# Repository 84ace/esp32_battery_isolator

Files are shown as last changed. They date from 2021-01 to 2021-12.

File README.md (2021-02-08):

<!-- PROJECT SHIELDS -->
<!--
*** I'm using markdown "reference style" links for readability.
*** Reference links are enclosed in brackets [ ] instead of parentheses ( ).
*** See the bottom of this document for the declaration of the reference variables
*** for contributors-url, forks-url, etc. This is an optional, concise syntax you may use.
*** https://www.markdownguide.org/basic-syntax/#reference-style-links
-->
[][contributors-url]
[][forks-url]
[][stars-url]
[][issues-url]
[][license-url]
[][linkedin-url]

<!-- PROJECT LOGO -->
<br />
<p align="center">
  <a href="https://github.com/84ace/esp32_battery_isolator">
    
  </a>

  <h3 align="center">ESP32 Battery Isolator</h3>

  <p align="center">
    Off-road battery management
    <br />
    <a href="https://github.com/84ace/esp32_battery_isolator/wiki"><strong>Explore the docs »</strong></a>
    <br />
    <br />
    <a href="https://github.com/84ace/esp32_battery_isolator/tree/master/board_images">Board Images</a>
    ·
    <a href="https://github.com/84ace/esp32_battery_isolator/issues">Report Bug</a>
    ·
    <a href="https://github.com/84ace/esp32_battery_isolator/issues">Request Feature</a>
  </p>
</p>

<!-- TABLE OF CONTENTS -->
<details open="open">
  <summary>Table of Contents</summary>
  <ol>
    <li>
      <a href="#about-the-project">About The Project</a>
      <ul>
        <li><a href="#main-features">Main Features</a></li>
        <li><a href="#whats-missing">What's Missing</a></li>
      </ul>
    </li>
    <li>
      <a href="#get-the-isolator">Get the Isolator</a>
    </li>
    <li><a href="#roadmap">Roadmap</a></li>
    <li><a href="#contributing">Contributing</a></li>
    <li><a href="#made-with">Made with</a></li>
    <li><a href="#license">License</a></li>
    <li><a href="#contact">Contact</a></li>
    <li><a href="#acknowledgements">Acknowledgements</a></li>
  </ol>
</details>

<!-- ABOUT THE PROJECT -->
## About The Project

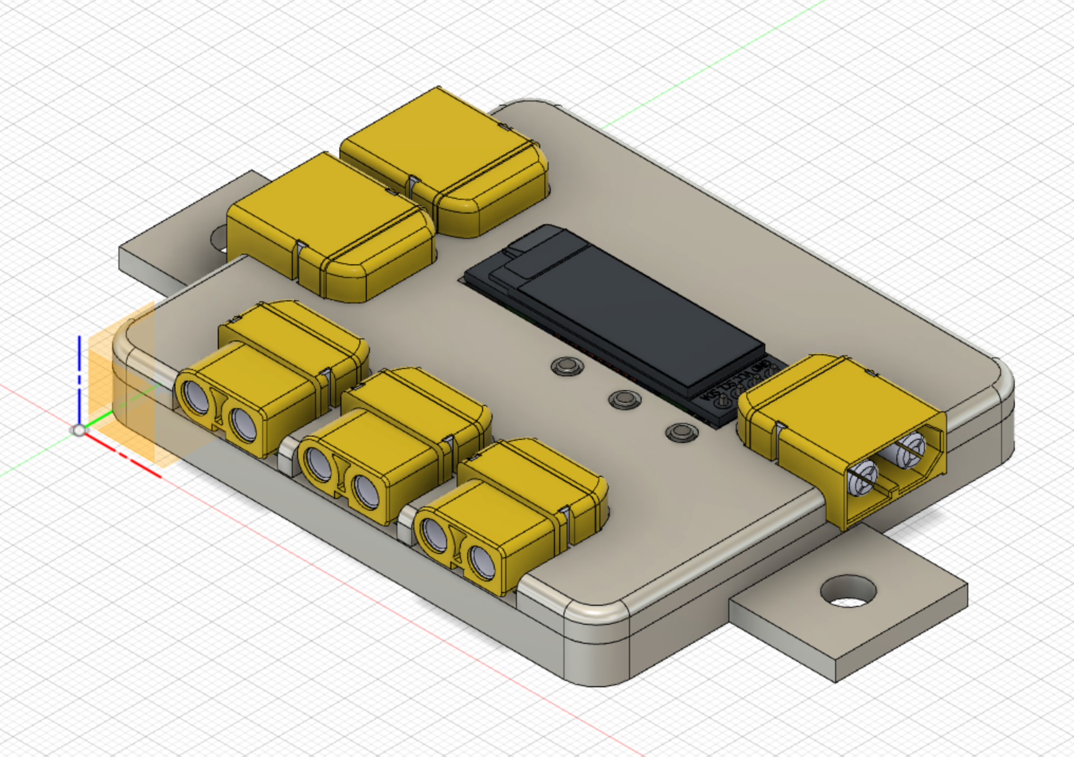
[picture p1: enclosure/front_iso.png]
ESP32 Battery Isolator
[](https://github.com/84ace/esp32_battery_isolator/raw/master/enclosure/front_iso.png)

The ESP32 Battery Isolator was created so that I could have better control over battery and load isolation, and because I thought it would be an interesting project that would allow me to learn a few new things. 

I also thought that I should be able to turn the lights off in camp from the comfort of bed, rather than having to turn the lights off and walk to bed in the dark and probably kick my toe.

<!-- MAIN FEATURES -->
## Main Features:
* Dual battery input
* Triple load output
* Charger input (From external MPPT/solar charge controller)
* Current sensors
* Temperature sensor
* 128x32 OLED screen
* Bluetooth (for remote control via phone app)
* WiFi (for debugging)
* USB (micro)
* 30A continuous operation

<!-- WHAT"S MISSING -->
## What's missing:
* A Phone app for remote control / live telemetry

If you would like to contribute an app please contact me via the <a href="https://github.com/84ace/esp32_battery_isolator/tree/master/board_images">issues</a> page.

<!-- GETTING STARTED -->
## Get the Isolator

There are two ways to get started with the ESP32 Battery Isolator: 
* You can either take the easy(er) way and buy a pre-made unit from [here](https://placeholder.com/) 
* you can send the gerber files off to your favourite fab house, order the components, assemble the board and print the enclosure yourself.

Your choice!

<!-- ROADMAP -->
## Roadmap

See the [open issues](https://github.com/84ace/esp32_battery_isolator/issues) for a list of proposed features (and known issues).

<!-- CONTRIBUTING -->
## Contributing

Contributions are what make the open source community such an amazing place to be learn, inspire, and create. Any contributions you make are **greatly appreciated**.

1. Fork the Project
2. Create your Feature Branch (`git checkout -b feature/AmazingFeature`)
3. Commit your Changes (`git commit -m 'Add some AmazingFeature'`)
4. Push to the Branch (`git push origin feature/AmazingFeature`)
5. Open a Pull Request

<!-- MADE WITH -->
## Made With:
* [KiCad - Electronic Design Automation Suite](https://kicad.org/)
* [Fusion360 - CAD Software](https://www.autodesk.com.au/products/fusion-360/overview)
* [JLCPCB - PCB Fabrication Manufacturer](https://jlcpcb.com/)

<!-- LICENSE -->
## License

Distributed under the MIT License. See `LICENSE` for more information.

<!-- CONTACT -->
## Contact

84ace - [@Racea_Quigg](https://twitter.com/@RaceaQuigg)

Project Link: [https://github.com/84ace/esp32_battery_isolator](https://github.com/84ace)

<!-- MARKDOWN LINKS & IMAGES -->
<!-- https://www.markdownguide.org/basic-syntax/#reference-style-links -->
[contributors-shield]: https://img.shields.io/github/contributors/84ace/esp32_battery_isolator.svg?style=for-the-badge
[contributors-url]: https://github.com/84ace/esp32_battery_isolator/graphs/contributors
[forks-shield]: https://img.shields.io/github/forks/84ace/esp32_battery_isolator.svg?style=for-the-badge
[forks-url]: https://github.com/84ace/esp32_battery_isolator/network/members
[stars-shield]: https://img.shields.io/github/stars/84ace/esp32_battery_isolator.svg?style=for-the-badge
[stars-url]: https://github.com/84ace/esp32_battery_isolator/stargazers
[issues-shield]: https://img.shields.io/github/issues/84ace/esp32_battery_isolator.svg?style=for-the-badge
[issues-url]: https://github.com/84ace/esp32_battery_isolator/issues
[license-shield]: https://img.shields.io/github/license/84ace/esp32_battery_isolator.svg?style=for-the-badge
[license-url]: https://github.com/84ace/esp32_battery_isolator/blob/master/LICENSE.txt
[linkedin-shield]: https://img.shields.io/badge/-LinkedIn-black.svg?style=for-the-badge&logo=linkedin&colorB=555
[linkedin-url]: https://www.linkedin.com/in/acea-quigg-2007036b/
[product-screenshot]: enclosure/front_iso.png

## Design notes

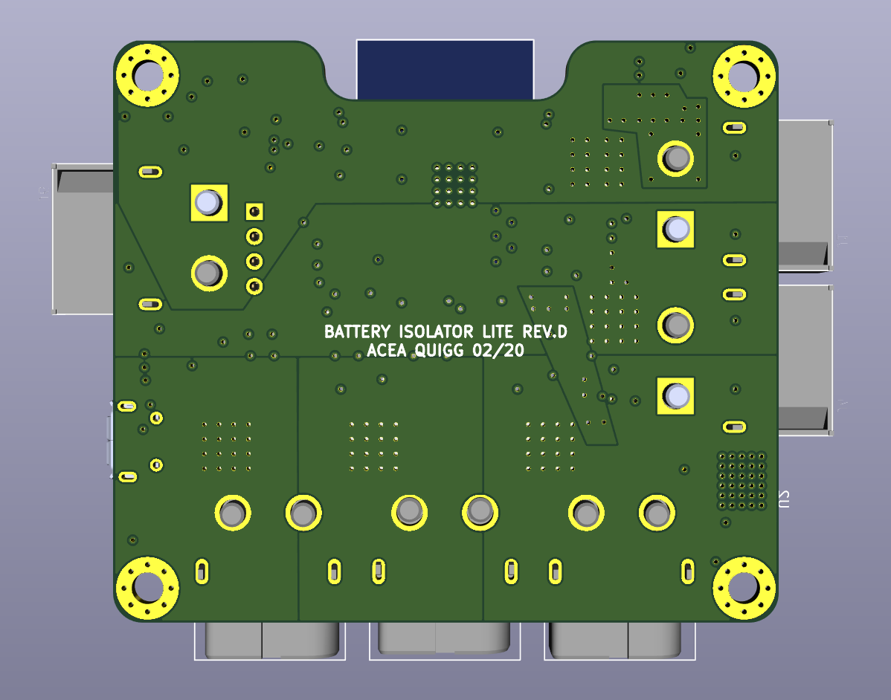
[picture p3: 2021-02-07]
board_images/back.png

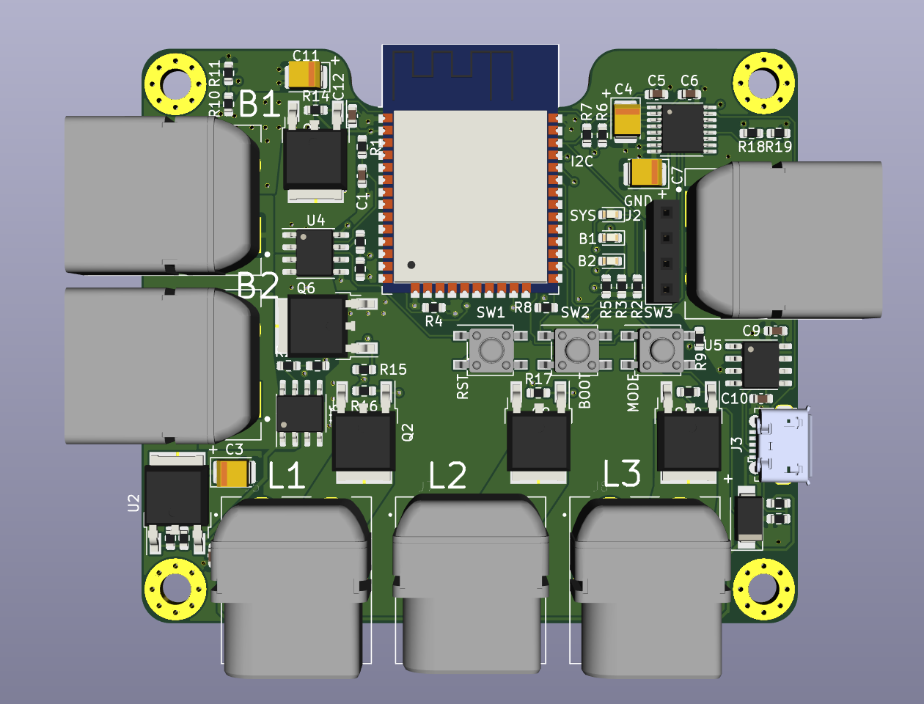
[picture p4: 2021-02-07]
board_images/front.png

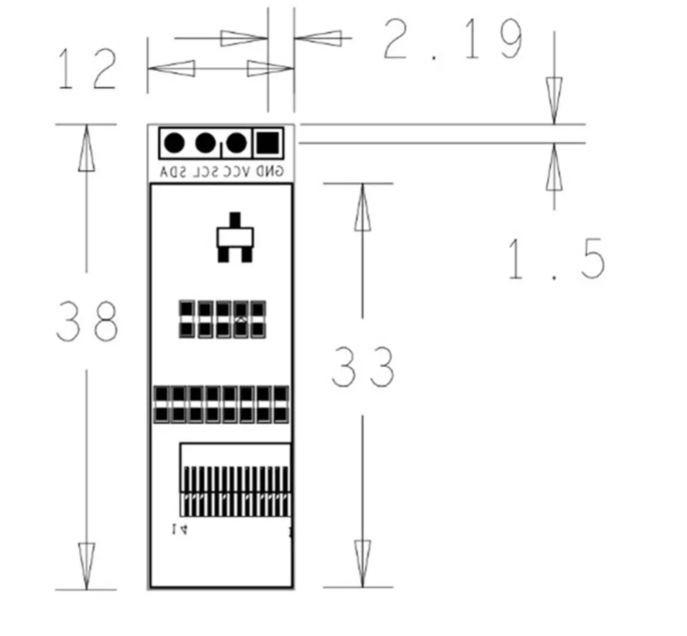
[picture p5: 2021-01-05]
enclosure/OLED_dimensions.png

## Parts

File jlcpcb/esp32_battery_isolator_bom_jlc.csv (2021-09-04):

Comment | Designator | Footprint | LCSC Part #
10nF | C2 | C_0603_1608Metric | C57112
220uF | C3 | C_Elec_6.3x7.7 | C371974
1uF | C4,C7 | CP_EIA-3528-21_Kemet-B | C169224
220uF | C8 | CP_EIA-3528-15_AVX-H | C30242
100n | C12,C1,C5,C6,C10,C9 | C_0603_1608Metric | C14663
4.7uF | C15 | C_0805_2012Metric | C1779
SS34 | D1 | D_SMA | C8678
LED_Small | D4 | LED_0603_1608Metric | C2286
B5819W | D8,D9,D3,D2 | D_SOD-123 | C8598
BATT1 | J1 | AMASS_XT60PW-M | C98732
USB_B_Micro | J3 | USB_Micro_SHOU-HAN-MicroXNJ_C404969_Horizontal | C404969
BATT2 | J4 | AMASS_XT60PW-M | C98732
LOAD1 | J5 | AMASS_XT60PW-F | C428722
CHGR | J6 | AMASS_XT60PW-M | C98732
LOAD2 | J7 | AMASS_XT60PW-F | C428722
LOAD3 | J8 | AMASS_XT60PW-F | C428722
Conn_01x03_Male | J9 | JST_SH_SM03B-SRSS-TB_1x03-1MP_P1.00mm_Horizontal | C160403
47uH | L1 | L_Bourns_SRN6045TA | C36414
MMBT3904 | Q1,Q7,Q9,Q5,Q12,Q3 | SOT-23 | C20526
AONR21321 | Q2,Q8,Q10,Q6,Q4,Q11,Q13 | TRANS_AONR21321 | C431196
200k | R10,R12,R20,R17,R16,R14,R15 | R_0603_1608Metric | C25811
33k | R11,R13 | R_0603_1608Metric | C4216
3.6k | R18,R21,R23,R6,R7,R3 | R_0603_1608Metric | C22980
11k | R19,R22,R24,R1,R8,R4,R2,R9,R5,R25,R26,R33,R32 | R_0603_1608Metric | C25950
510R | R27,R29,R28,R30,R31 | R_0603_1608Metric | C269885
C492887 | SW1,SW2 | TS4550TP | C492887
ESP32-WROOM-32D | U1 | ESP32-WROOM-32 | C473012
XL1509_SOP8 | U2 | SOIC-8_3.9x4.9mm_P1.27mm | C2681226
ADC128D818 | U3 | TSSOP-16_4.4x5mm_P0.65mm | C139062
CH340N | U5 | SOIC-8_3.9x4.9mm_P1.27mm | C506813
CC6903SO-30A | U6,U4 | SOP-8_3.9x4.9mm_P1.27mm | C469388

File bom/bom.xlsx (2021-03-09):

References | lcsc_part_number | Value | Footprint | Quantity
C1, C2, C5, C6, C9, C10, C12 | C14663 | 100n | C_0603_1608Metric | 7
C3, C4, C7, C11 | C169224 | 1uF | CP_EIA-3528-21_Kemet-B | 4
R11, R13 | C4216 | 33k | R_0603_1608Metric | 2
R2, R3, R5, R6, R7, R18, R21, R23 | C22980 | 3.6k | R_0603_1608Metric | 8
R26 | C23138 | 330R | R_0603_1608Metric | 1
R10, R12, R14, R15, R16, R17, R20 | C25811 | 200k | R_0603_1608Metric | 7
R1, R4, R8, R9, R19, R22, R24 | C25950 | 11k | R_0603_1608Metric | 7
R25 | C8218 | 200R | R_0603_1608Metric | 1
D1, D3, D4 | C2286 | MAIN LED | LED_0603_1608Metric | 3
D2 | C2480 | SS14 | D_SMA | 1
U5 | C108996 | CH330N | SOIC-8_3.9x4.9mm_P1.27mm | 1
U3 | C139062 | ADC128D818 | TSSOP-16_4.4x5mm_P0.65mm | 1
U4, U6 | C469388 | CC6903SO-30A | SOP-8_3.9x4.9mm_P1.27mm | 2
U1 | C473012 | ESP32-WROOM-32D | ESP32-WROOM-32 | 1
U2 | C75510 | LM317AG-TN3-R | TO-252-2 | 1
SW1, SW2, SW3 | C492887 | C492887 | TS4550TP | 3
Q2, Q4, Q6, Q8, Q10 | C124530 | AP6679GH-HF | TO-252-2 | 5
J2 |  | Conn_01x04_Female | PinSocket_1x04_P2.54mm_Vertical | 1
J3 | C404969 | USB_B_Micro | USB_Micro_SHOU-HAN-MicroXNJ_C404969_Horizontal | 1
J5 | C428722 | LOAD1 | AMASS_XT60PW-F | 1
J7 | C428722 | LOAD2 | AMASS_XT60PW-F | 1
J8 | C428722 | LOAD3 | AMASS_XT60PW-F | 1
J1 | C98732 | BATT1 | AMASS_XT60PW-M | 1
J4 | C98732 | BATT2 | AMASS_XT60PW-M | 1
J6 | C98732 | CHGR | AMASS_XT60PW-M | 1

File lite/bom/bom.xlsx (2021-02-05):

References | lcsc_part_number | mfr_part_number | package | Value | Footprint | Quantity
BI:C1, C5, C6, C12, C9, C10 | C128353 | 0805B104K250 | 0805 | 100n | C_0805_2012Metric | 6
BI:C2, C3 | C23289 | RVT1V220M0505 | 5x5.4 | 22uF 35V | C_Elec_5x5.4 | 2
BI:C4, C7, C11 | C126949 | CA45-A035K105T | CASE_A_3216 | 1uF | CP_EIA-3216-18_Kemet-A | 3
BI:D1, D3, D4 | C72044 | 19-217/R6C-AL1M2VY/3T | 0603 | RED LEDs | LED_0603_1608Metric | 1
BI:D2 | C2480 | SS14 | SMA | SS14 | D_SMA | 1
BI:J3 | C319172 | U253-051T-4BH89-F1B | micro_usb | USB_B_Micro | USB_Micro-B_XKB_4BH89_SMT | 1
BI:J1,J4, J6 | C98733 (https://lcsc.com/product-detail/Power-Connectors_Changzhou-Amass-Elec-XT60_C98733.html) | XT60-F |  | BATT2 | AMASS_XT60-F_1x02_P7.20mm_Vertical | 3
BI:J5, J7, J8 | C98734 | XT60-M |  | LOAD1 | AMASS_XT60-M_1x02_P7.20mm_Vertical | 3
BI:Q2, Q4, Q6, Q8, Q10 | C148395 | WSD20L120DN | SON8 | WSD20L120DN | PowerPAK_SO-8_Single | 5
BI:R1, R4, R8, R9, R19, R22, R24 | C705802 | RT0603BRE0710K2L | 0603 | 10k2 | R_0603_1608Metric | 7
BI:R10, R12, R14, R15, R16, R17, R20 | C491109 | ERA3AEB1053V | 0603 | 105k | R_0603_1608Metric | 7
BI:R11, R13 | C319766 | AR03BTCX2002 | 0603 | 20k | R_0603_1608Metric | 2
BI:R18, R21, R23 | C23022 | 0603WAF3092T5E | 0603 | 30k9 | R_0603_1608Metric | 3
BI:R2, R3, R5, R6, R7 | C304726 | RS-03K2551FT | 0603 | 2.55K | LED_0603_1608Metric | 3
BI:SW1, SW2, SW3 | C72443 | KMR221GLFS | KMR2 | KMR221GLFS | SW_Push_1P1T_NO_CK_KMR2 | 3
BI:U1 | C473012 | ESP32-WROOM-32D | SMD-38 | ESP32-WROOM-32D | ESP32-WROOM-32 | 1
BI:U2 | C12051 | LD1086DT33TR | TO-252-2(DPAK) | LD1086D2T33TR | TO-252-2 | 1
BI:U3 | C139062 | ADC128D818CIMTX | TSSOP-16 | ADC128D818 | TSSOP-16_4.4x5mm_P0.65mm | 1
BI:U4, U6 | C469388 | CC6903SO-30A\r | SOP-8 | CC6903SO-30A | SOP-8_3.9x4.9mm_P1.27mm | 2
BI:U5 | C108996 | CH330N | SOP-8 | CH330N | SOIC-8_3.9x4.9mm_P1.27mm | 1

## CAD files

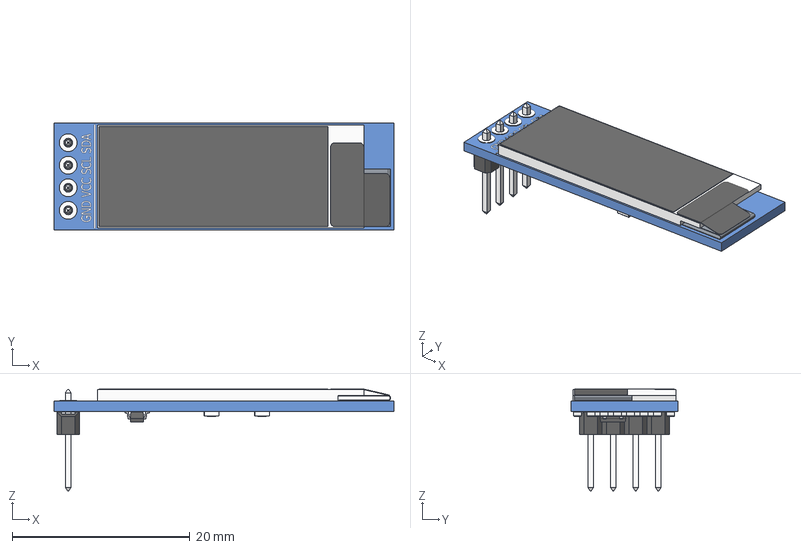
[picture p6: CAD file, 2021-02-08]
3d_model/OLED_0.91_128x32.step
38.3 x 12.1 x 11.5 mm
OLED_0.91_128x32
Pin Header 4 x 1 TH 2.54mm Pitch
RESC-0603 x 13
2SD0601A

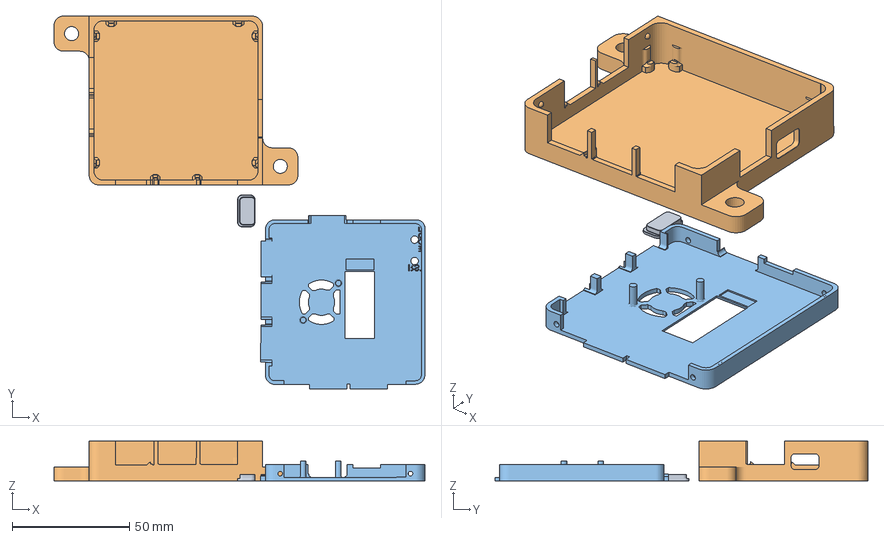
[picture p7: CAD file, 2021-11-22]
enclosure/revg/REV_G.3mf
158.2 x 159.0 x 16.9 mm
USB cap.stl
Bottom.stl
Top.stl

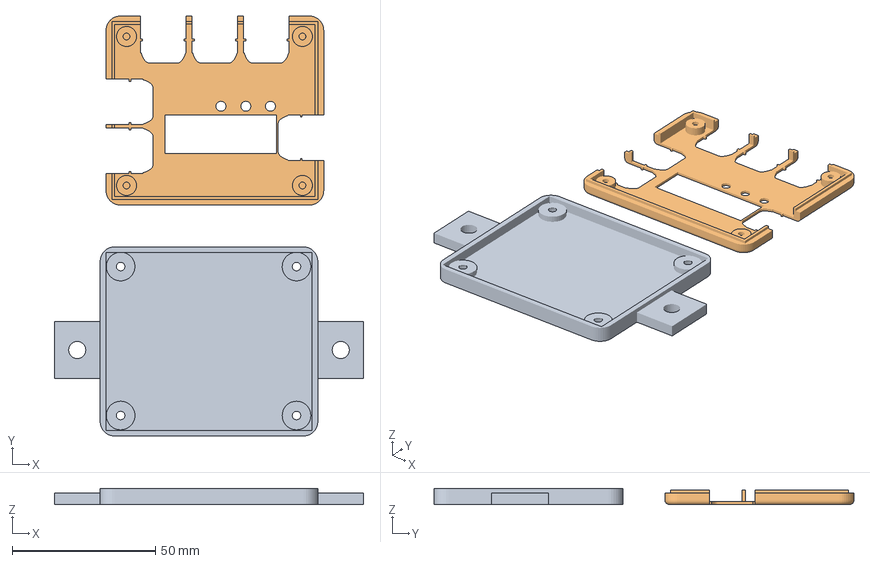
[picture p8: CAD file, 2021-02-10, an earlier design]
enclosure/revd/REV_D.3mf
108.0 x 146.6 x 5.60 mm
e16b49ae-1aed-4ee6-b51c-7ca3a6dbe336.stl
ccecfdcf-7b8e-40b3-9f25-145435015e84.stl

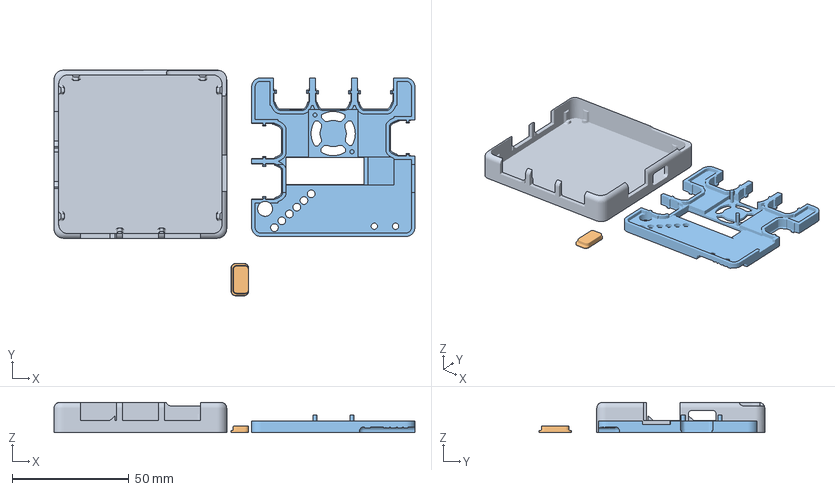
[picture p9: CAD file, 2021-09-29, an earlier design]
enclosure/revf/PrusaSlicer_project.3mf
154.6 x 96.7 x 13.0 mm
Bottom.stl
USB cap.stl
Top.stl

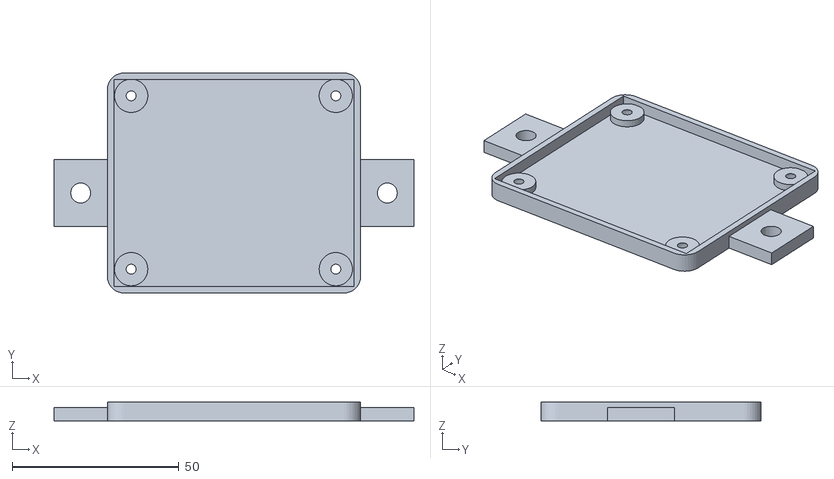
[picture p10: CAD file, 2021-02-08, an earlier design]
enclosure/revd/back.stl
108.0 x 66.0 x 5.60

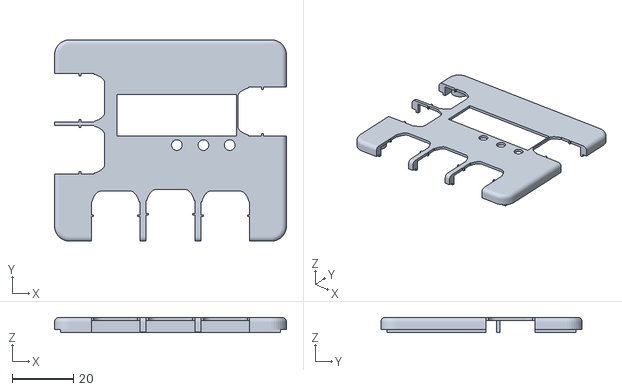
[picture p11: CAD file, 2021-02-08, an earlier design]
enclosure/revd/front.stl
76.0 x 66.0 x 5.00

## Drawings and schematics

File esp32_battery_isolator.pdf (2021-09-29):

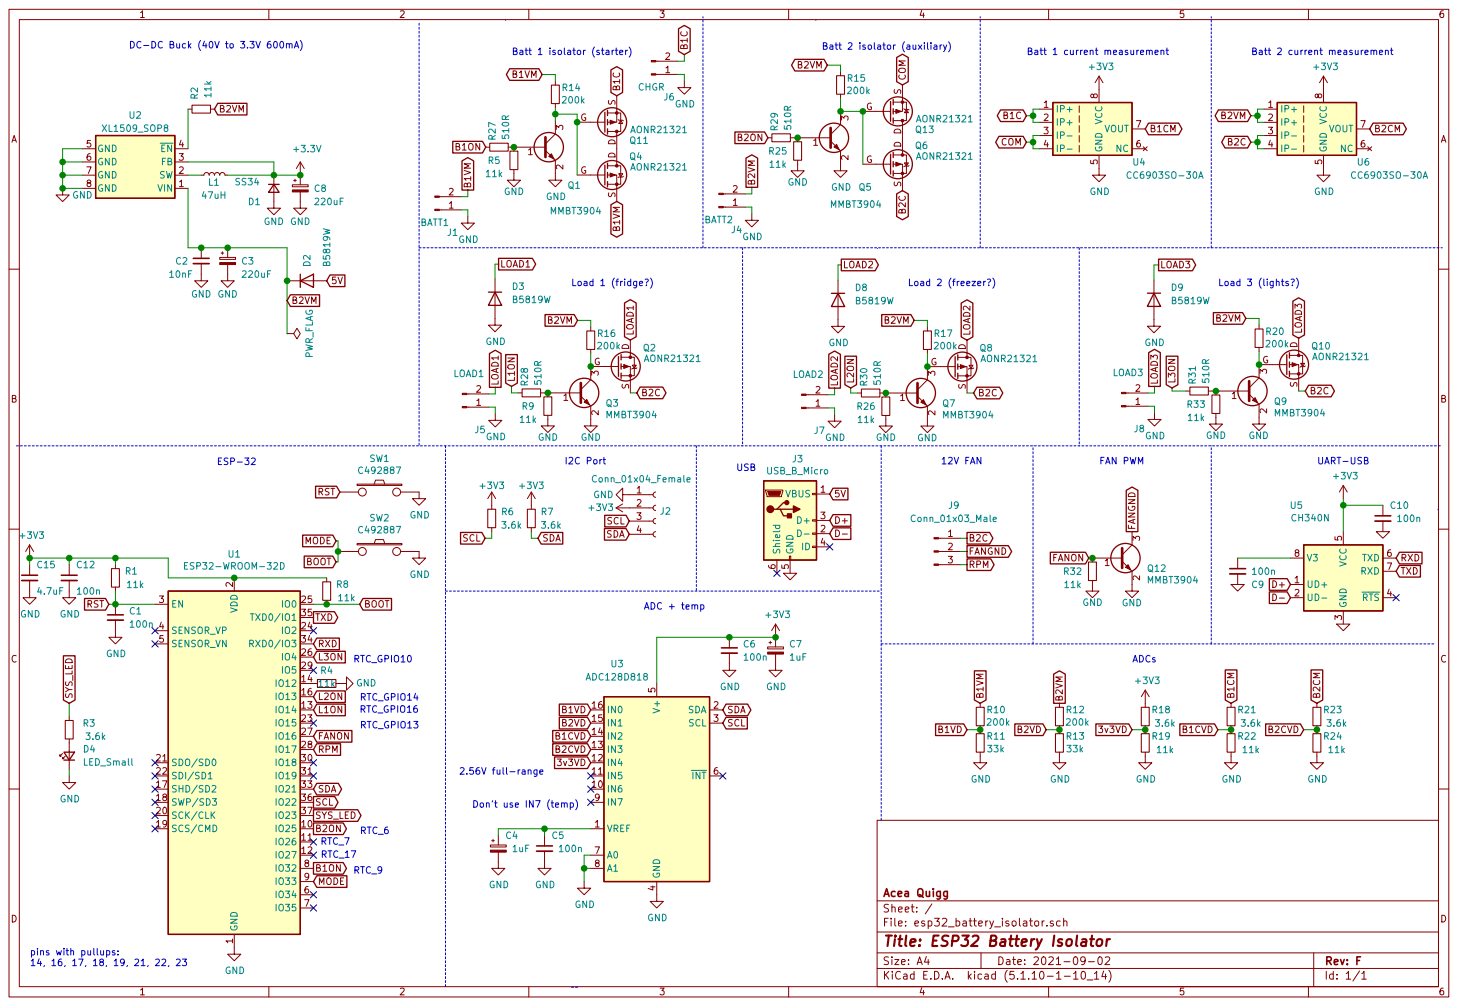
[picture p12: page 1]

DC-DC Buck (40V to 3.3V 600mA)

2 SCK/CLK 20 SDO/SD0 21 SDI/SD1 22

File: esp32_battery_isolator.sch Sheet: / Acea Quigg GND GND

Id: 1/1 Title: ESP32 Battery Isolator

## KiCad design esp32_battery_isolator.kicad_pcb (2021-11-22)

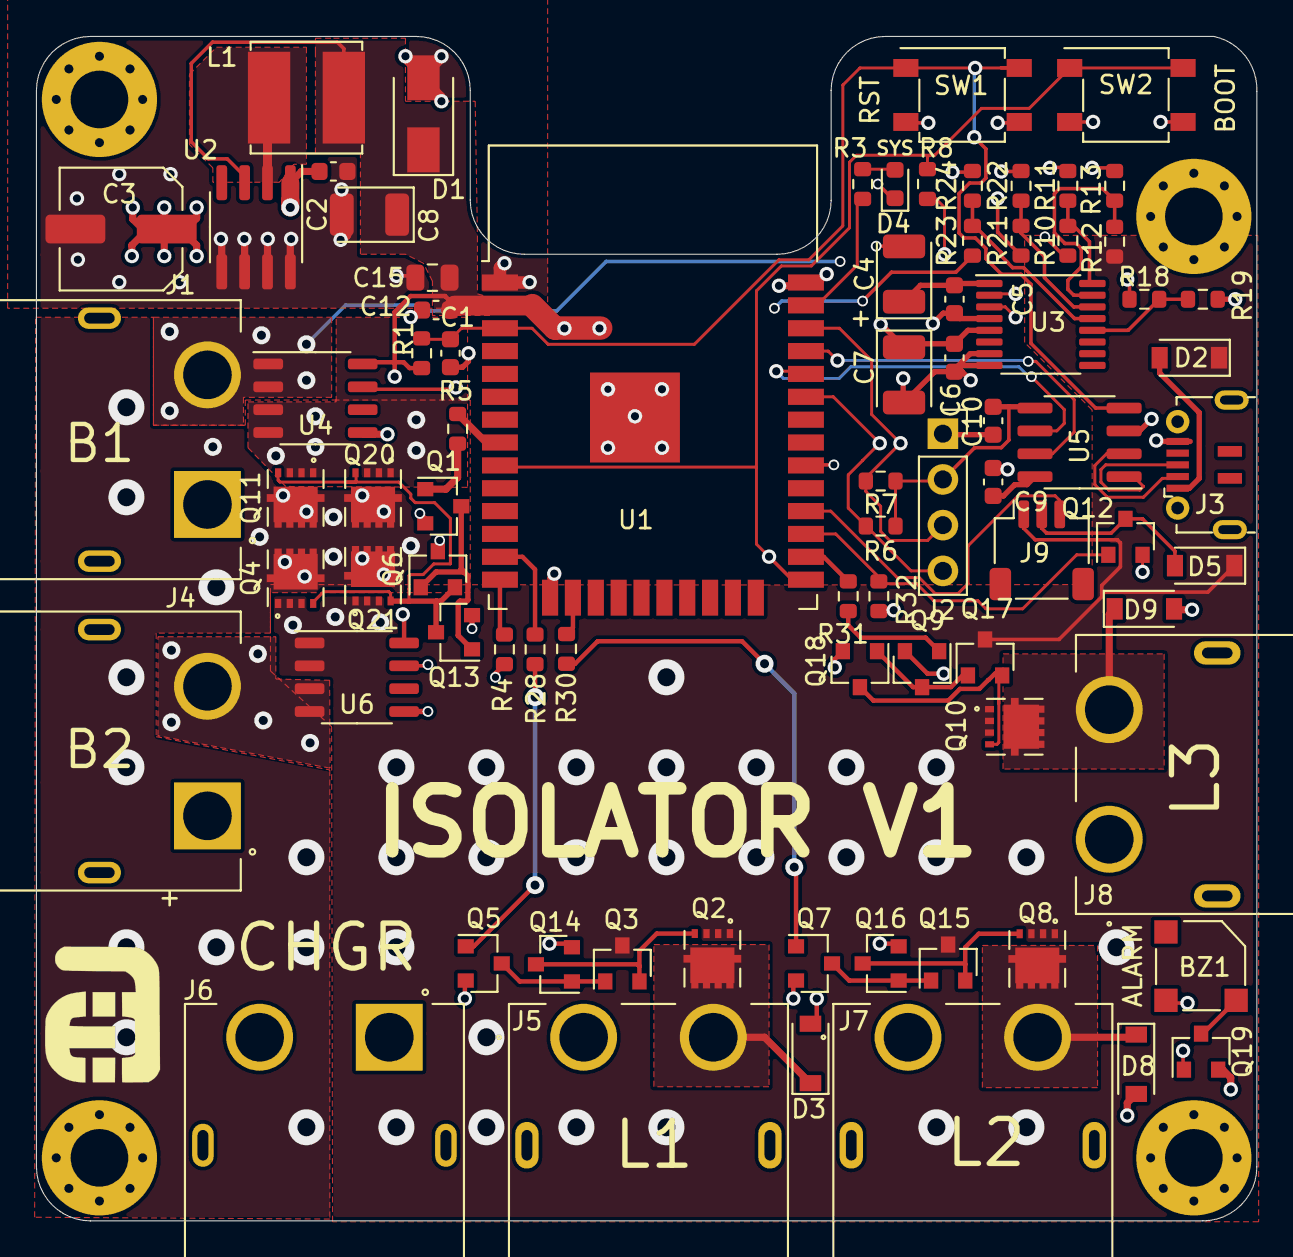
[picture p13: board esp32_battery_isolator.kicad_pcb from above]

Board: 4 copper layers, 67.8 x 65.8 mm, 85 parts (0 on the bottom side), 53 nets.

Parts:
BZ1: Buzzer; SMDBuzzer_C201046
C1, C5, C6, C9, C10, C12: 100n; C_0603_1608Metric
C2: 1uF; C_0603_1608Metric
C3: 220uF; C_Elec_6.3x7.7
C4, C7: 1uF; CP_EIA-3528-21_Kemet-B
C8: 220uF; CP_EIA-3528-15_AVX-H
C15: 4.7uF; C_0805_2012Metric
D1: SS34; D_SMA
D2, D3, D5, D8, D9: B5819W; D_SOD-123
D4: LED_Small; LED_0603_1608Metric
H1, H1#2, H1#3, H1#4: MountingHole_3.2mm_M3_Pad_Via
J1: BATT1; AMASS_XT60PW-M
J2: Conn_01x04_Female; PinSocket_1x04_P2.54mm_Vertical
J3: USB_B_Micro; USB_Micro_SHOU-HAN-MicroXNJ_C404969_Horizontal
J4: BATT2; AMASS_XT60PW-M
J5: LOAD1; AMASS_XT60PW-F
J6: CHGR; AMASS_XT60PW-M
J7: LOAD2; AMASS_XT60PW-F
J8: LOAD3; AMASS_XT60PW-F
J9: Conn_01x03_Male; JST_SH_SM03B-SRSS-TB_1x03-1MP_P1.00mm_Horizontal
L1: 47uH; L_Bourns_SRN6045TA
Q1, Q3, Q5, Q6, Q7, Q9, Q12, Q15, Q17, Q19: MMBT3904; SOT-23
Q2, Q4, Q8, Q10, Q11, Q20, Q21: AONR21357; DFN-TRANS_AONR21321
Q13, Q14, Q16, Q18: MMBT3906; SOT-23
R1, R4, R8, R19, R22, R24, R32: 11k; R_0603_1608Metric
R3, R6, R7, R18, R21, R23: 3.6k; R_0603_1608Metric
R5, R28, R30, R31: 510R; R_0603_1608Metric
R10, R12: 200k; R_0603_1608Metric
R11, R13: 33k; R_0603_1608Metric
Ref**: Val**; aces_electronics_small
SW1, SW2: C480325; TS4550TP
U1: ESP32-WROOM-32D; ESP32-WROOM-32
U2: XL1509_SOP8; SOIC-8_3.9x4.9mm_P1.27mm
U3: ADC128D818; TSSOP-16_4.4x5mm_P0.65mm
U4, U6: CC6903SO-30A; SOP-8_3.9x4.9mm_P1.27mm
U5: CH340N; SOIC-8_3.9x4.9mm_P1.27mm

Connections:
3v3VD: R18.2, R19.1, U3.12
5V: D2.2, J3.1
+3V3: BZ1.2, C6.1, C7.1, C8.1, C10.1, C12.1, C15.1, D1.1, J2.2, L1.2, R1.1, R6.1, R7.1, R8.1, R18.1, U1.2, U2.3, U3.5, U4.8, U5.5, U6.8
B1C: J6.2, Q11.S, Q20.S, U4.3, U4.4
B1CM: R21.1, U4.7
B1CVD: R21.2, R22.1, U3.14
B1ON: R5.1, U1.8
B1VD: R10.2, R11.1, U3.16
B1VM: J1.2, R10.1, U4.1, U4.2
B2CM: R23.1, U6.7
B2CVD: R23.2, R24.1, U3.13
B2VD: R12.2, R13.1, U3.15
BOOT: R8.2, SW2.1, U1.9, U1.25
BZR: Q19.1, U1.30
COM: C2.1, C3.1, D2.1, D5.1, J9.1, Q2.S, Q3.3, Q4.S, Q6.3, Q8.S, Q10.S, Q15.3, Q17.3, Q21.S, R12.1, U2.1, U6.1, U6.2
D: Q4.D, Q11.D, Q20.D, Q21.D
D+: J3.3, U5.1
D-: J3.2, U5.2
FANGND: D5.2, J9.2, Q12.3
FANON: Q12.1, R32.1, U1.27
G: Q4.G, Q6.2, Q11.G, Q13.3, Q20.G, Q21.G
GND: C1.2, C2.2, C3.2, C4.2, C5.2, C6.2, C7.2, C8.2, C9.2, C10.2, C12.2, C15.2, D1.2, D3.2, D4.1, D8.2, D9.2, J1.1, J2.1, J3.5, J4.1, J5.1, J6.1, J7.1, J8.1, Q1.2, Q5.2, Q7.2, Q9.2, Q12.2, Q13.2, Q14.2, Q16.2, Q18.2, Q19.2, R4.1, R11.2, R13.2, R19.2, R22.2, R24.2, R32.2, SW1.2, SW2.2, U1.1, U1.15, U1.38, U1.39, U2.5, U2.6, U2.7, U2.8, U3.4, U3.7, U3.8, U4.5, U5.3, U6.5
L1ON: R28.1, U1.13
L2ON: R30.1, U1.16
L3ON: R31.1, U1.26
LOAD1: D3.1, J5.2, Q2.D
LOAD2: D8.1, J7.2, Q8.D
LOAD3: D9.1, J8.2, Q10.D
unnamed: BZ1.1, Q19.3
unnamed: C4.1, C5.1, U3.1
unnamed: C9.1, U5.8
unnamed: D4.2, R3.2
unnamed: J4.2, U6.3, U6.4
unnamed: L1.1, U2.2
unnamed: Q1.1, R5.2
unnamed: Q1.3, Q6.1, Q13.1
unnamed: Q5.1, R28.2
unnamed: Q7.1, R30.2
unnamed: Q9.1, R31.2
unnamed: Q10.G, Q17.2, Q18.3
unnamed: Q3.1, Q5.3, Q14.1
unnamed: Q2.G, Q3.2, Q14.3
unnamed: Q7.3, Q15.1, Q16.1
unnamed: Q8.G, Q15.2, Q16.3
unnamed: Q9.3, Q17.1, Q18.1
unnamed: R4.2, U1.14
RPM: J9.3, U1.28
RST: C1.1, R1.2, SW1.1, U1.3, U5.4
RXD: U1.34, U5.6
SCL: J2.3, R6.2, U1.36, U3.3
SDA: J2.4, R7.2, U1.33, U3.2
SYS_LED: R3.1, U1.37
TXD: U1.35, U5.7

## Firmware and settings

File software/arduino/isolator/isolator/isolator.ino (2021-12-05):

#define BLYNK_USE_DIRECT_CONNECT

/* Comment this out to disable prints and save space */
#define BLYNK_PRINT Serial

#include "Wire.h"
#include "ADC128D818.h"
#include <SPI.h>
#include <Adafruit_GFX.h>
#include <Adafruit_SSD1306.h>
#include <BlynkSimpleEsp32_BLE.h>
#include <BLEDevice.h>
#include <BLEServer.h>
#include <WiFi.h>
#include <WiFiClient.h>
#include <WebServer.h>
#include <ESPmDNS.h>
#include <Update.h>
#include "OneButton.h"

/* Fill-in your Template ID (only if using Blynk.Cloud) */
//#define BLYNK_TEMPLATE_ID   "YourTemplateID"

#define SCREEN_WIDTH 128    // OLED display width, in pixels
#define SCREEN_HEIGHT 32    // OLED display height, in pixels
#define OLED_RESET 4        // Reset pin # (or -1 if sharing Arduino reset pin)
#define SCREEN_ADDRESS 0x3C ///< See datasheet for Address; 0x3D for 128x64, 0x3C for 128x32

//const char auth[] = "pX5sSlM-W175Zs_KnO9OHuXQ-55sdPdU"; // Acea's token
const char auth[] = "KkZ2Pvq4-I8aNwZjsOCtiQJzL8I8NYvO"; // Warren's token

char version[] = "v001";

char sw_version[] = "20211127";
const char *host = "isolator";
const char *ssid = "isolator";
const char *password = "isolator";

bool debugVoltages = false; // ToDo: move this into setup and catch a button press to enable
bool debugBLE = false;
bool debugPWM = true;
bool debugTemp = false;
bool debugAppCommands = false;
bool debugTiming = false;
bool menuDebug = false;
bool notificationsOn = true;
bool notificationAllowed = true;

const int maxAllowedBoardTemp = 84;
float battery1CurrentLimit = 25.00;
float battery2CurrentLimit = 25.00;
int b1CurrentLimited = 0;
int b2CurrentLimited = 0;
int temperatureLimited = 0;
unsigned long startMillis = 0;
unsigned long currentMillis = 0;
unsigned long carStartingTimer = 0;
unsigned b1LoadDebounceTimer = 0;
unsigned b2LoadDebounceTimer = 0;
int carStarting = 0;
String channelName;

#define REVG // board hardware version (written on the back of the PCB)
#ifdef REVG
const int buttonPin = 33; // Mode button
const int sysLED = 23;    // SYS LED (red, 1Hz blink)
const int b1EnPin = 32;   // connection to starter battery (32)
const int b2EnPin = 25;   // connection to auxiliary battery (25)
const int l1EnPin = 14;   // connection to Load 1 (Freezer) (14)
const int l2EnPin = 13;   // connection to Load 2 (Fridge) (13)
const int l3EnPin = 4;    // Connection to Load 3 (Lights) (4)
const int fanEnPin = 16;  // PWM fan in case
// need to write the code for the buzzer
const int buzzerEnPin = 18;  // buzzer on PCB
#endif

int sysLEDState = 0;

float systemVoltageDivider = 1.322;
float currentVoltageDivider = 1.33;
float batteryVoltageDivider = 7.139;
float milliVoltPerAmp = 0.045;

float systemVoltage = 0.00;
float systemTemperature = 25.00;
float battery1Voltage = 13.00;
float battery2Voltage = 13.00;
float battery1Current = 0.00;
float battery2Current = 0.00;
float battery1VoltageMin = 15.00;
float battery2VoltageMin = 15.00;
float battery1VoltageMax = 0.00;
float battery2VoltageMax = 0.00;
float battery1CurrentMin = 25.00;
float battery2CurrentMin = 25.00;
float battery1CurrentMax = -25.00;
float battery2CurrentMax = -25.00;
int ioControlLoop = 0;
int b1VSmoother = 0;
int b2VSmoother = 0;
int maxPWMVal = 255; // full range at 50Hz
int minPWMVal = 0;   // full range at 50Hz
int battery1PWMVal = 255;
int battery2PWMVal = 255;
int l1PWMVal = 255;
int l2PWMVal = 255;
int l3PWMVal = 255;
int fanPWMVal = 255;
const int freq = 125; // 400Hz
const int b2PWMChannel = 2;
const int l1PWMChannel = 3;
const int l2PWMChannel = 4;
const int l3PWMChannel = 5;
const int fanPWMChannel = 6;
const int resolution = 8;
bool smallText = false;
bool suspendOLEDUpdates = false;

int l0 = 0;
int l1 = 0;
int l2 = 0;
int l3 = 0;
int l4 = 0;
bool singlePress = false;
bool doublePress = false;
int multiPress = 0;
bool longPress = false;
bool menuMode = false;
bool menuOpen = false;
bool ioMenuMode = false;
bool b1MenuMode = false;
bool b1MenuAuto = false;
bool b2MenuMode = false;
bool l1MenuMode = false;
bool l2MenuMode = false;
bool l3MenuMode = false;
bool b1MenuOn = false;
bool b1MenuOff = false;
bool limitsMenuMode = false;
bool uploadMenuMode = false;

char staticTextToDisplay[22] = "";
char minBuffer[] = "-25.00";
char maxBuffer[] = "-25.00";

bool b1Healthy = 1;
bool b2Healthy = 1;
bool l1Healthy = 1;
bool l2Healthy = 1;
bool l3Healthy = 1;

int b1ForcedOn = 0;
int b2ForcedOn = 0;
int l1ForcedOn = 0;
int l2ForcedOn = 0;
int l3ForcedOff = 0;

int batchEvent = 0;
int OLEDEvent = 0;
int connectedToBlynk = 0;
extern bool appState;

int updatesInLoop = 5;

unsigned long previousTime = 0;
int days = 0;
int seconds = 0;
int minutes = 0;
int hours = 0;

WebServer server(80);

Adafruit_SSD1306 display = Adafruit_SSD1306(SCREEN_WIDTH, SCREEN_HEIGHT, &Wire, OLED_RESET);

ADC128D818 adc(0x1D);

BlynkTimer timer0;

OneButton button(buttonPin, true);

// save the millis when a button press has started.
unsigned long pressStartTime;

ICACHE_RAM_ATTR void checkTicks()
{
  // include all buttons here to be checked
  button.tick(); // just call tick() to check the state.
}

const char *serverIndex =
    "<p>Please upload a .bin file to upgrade your isolator.<p><p>Wait at least 60 seconds before freaking out, you will see the OLED start cycling again when it is done.<p><form method='POST' action='/update' enctype='multipart/form-data'><input type='file' name='update'><input type='submit' value='Update'></form>";

void PWMSetup()
{
  // configure LED PWM functionalitites
  ledcSetup(b2PWMChannel, freq, resolution);
  ledcSetup(l1PWMChannel, freq, resolution);
  ledcSetup(l2PWMChannel, freq, resolution);
  ledcSetup(l3PWMChannel, freq, resolution);
  ledcSetup(fanPWMChannel, freq, resolution);

  // attach the channel to the GPIO to be controlled
  ledcAttachPin(b2EnPin, b2PWMChannel);
  ledcAttachPin(l1EnPin, l1PWMChannel);
  ledcAttachPin(l2EnPin, l2PWMChannel);
  ledcAttachPin(l3EnPin, l3PWMChannel);
  ledcAttachPin(fanEnPin, fanPWMChannel);
}

void gpioSetup()
{
  pinMode(buttonPin, INPUT_PULLUP);
  pinMode(sysLED, OUTPUT);
  pinMode(b1EnPin, OUTPUT);
}

// this function will be called when the button was pressed 1 time only.
void singleClick()
{
  Serial.println("singleClick() detected.");
  singlePress = true;
  menuNavigator();
} // singleClick

// this function will be called when the button was pressed 2 times in a short timeframe.
void doubleClick()
{
  Serial.println("doubleClick() detected.");
  doublePress = true;
  menuNavigator();
} // doubleClick

// this function will be called when the button was pressed multiple times in a short timeframe.
void multiClick()
{
  Serial.print("multiClick(");
  Serial.print(button.getNumberClicks());
  Serial.println(") detected.");
  menuNavigator();
} // multiClick

// this function will be called when the button was held down for 1 second or more.
void pressStart()
{
  Serial.println("pressStart()");
  pressStartTime = millis() - 1000; // as set in setPressTicks()
} // pressStart()

// this function will be called when the button was released after a long hold.
void pressStop()
{
  Serial.print("longPress(");
  Serial.print(millis() - pressStartTime);
  Serial.println(") detected.");
  longPress = true;
  menuNavigator();
} // pressStop()

void staticText(char *line1, char *line2, char *line3 = "", char *line4 = "")
{
  display.clearDisplay();
  if (!smallText)
  {
    display.setTextSize(2);
  }
  else
  {
    display.setTextSize(1);
  }
  display.setTextColor(SSD1306_WHITE);
  display.setCursor(00, 0);
  display.println(F(line1));
  display.println(F(line2));
  display.println(F(line3));
  display.println(F(line4));
  display.display();
}

void timeKeeper()
{
  if (millis() >= (previousTime))
  {
    previousTime = previousTime + 1000;
    seconds = seconds + 1;
    if (seconds == 60)
    {
      seconds = 0;
      minutes = minutes + 1;
      b1LoadDebounceTimer = 0;
      b2LoadDebounceTimer = 0;
      if (debugPWM)
      {
        Serial.print("Seconds =60, debouncing to 0: ");
        Serial.println(b1LoadDebounceTimer);
      }
      ioControlLoop++;
    }
    if (minutes == 60)
    {
      minutes = 0;
      hours = hours + 1;
    }
    if ((hours == 8) || (hours == 16) || (hours == 24))
    {
      notificationAllowed = true; // only allow one notification per 8 hours
    }
    if (hours == 24)
    {
      hours = 0;
      days = days + 1;
      resetDailyCounters();
    }
    if (days == 28)
    {
      days = 0;
    }
    if (debugTiming)
    {
      Serial.print(days);
      Serial.print("d");
      Serial.print(hours);
      Serial.print("h");
      Serial.print(minutes);
      Serial.print("m");
      Serial.print(seconds);
      Serial.println("s");
    }
  }
  digitalWrite(sysLED, sysLEDState);
  sysLEDState = !sysLEDState;
}

void OLEDUpdater()
{
  if (!suspendOLEDUpdates)
  {
    if (OLEDEvent == 0)
    {
      dtostrf(systemTemperature, 3, 2, staticTextToDisplay);
      staticText("Temp (C):", staticTextToDisplay);
      OLEDEvent++;
    }
    else if (OLEDEvent == 1)
    {
      dtostrf(battery1Voltage, 3, 2, staticTextToDisplay);
      staticText("B1 (V):", staticTextToDisplay);
      OLEDEvent++;
    }
    else if (OLEDEvent == 2)
    {
      dtostrf(battery2Voltage, 3, 2, staticTextToDisplay);
      staticText("B2 (V):", staticTextToDisplay);
      OLEDEvent++;
    }
    else if (OLEDEvent == 3)
    {
      dtostrf(battery1Current, 3, 2, staticTextToDisplay);
      staticText("B1 (A):", staticTextToDisplay);
      OLEDEvent++;
    }
    else if (OLEDEvent == 4)
    {
      dtostrf(battery2Current, 3, 2, staticTextToDisplay);
      staticText("B2 (A):", staticTextToDisplay);
      OLEDEvent++;
    }
    else if (OLEDEvent == 5)
    {
      char SingleInt[21] = "00000000";
      char uptime[21] = "";
      char systemV[19] = "";
      char systemVText[19] = "";
      smallText = true;
      //memset(uptime,0,sizeof(uptime)); // ensure it's empty, probably redundant
      strcat(uptime, "Uptime: ");
      itoa(days, SingleInt, 10);
      strcat(uptime, SingleInt);
      strcat(uptime, "d");
      itoa(hours, SingleInt, 10);
      strcat(uptime, SingleInt);
      strcat(uptime, "h");
      itoa(minutes, SingleInt, 10);
      strcat(uptime, SingleInt);
      strcat(uptime, "m");
      itoa(seconds, SingleInt, 10);
      strcat(uptime, SingleInt);
      strcat(uptime, "s");

      strcat(systemV, "Sys Voltage:");
      dtostrf(systemVoltage, 6, 2, systemVText);
      strcat(systemV, systemVText);

      staticText("DEBUG:", uptime, systemV);
      smallText = false;
      OLEDEvent = 0;
    }
  }
}

void resetDailyCounters() 
{
  Serial.println("RESETTING DAILY COUNTERS");
  battery1VoltageMin = battery1VoltageMax;
  battery2VoltageMin = battery2VoltageMax;
  battery1VoltageMax = battery1VoltageMin;
  battery2VoltageMax = battery2VoltageMin;
  battery1CurrentMin = battery1CurrentMax;
  battery2CurrentMin = battery2CurrentMax;
  battery1CurrentMax = battery1CurrentMin;
  battery2CurrentMax = battery2CurrentMin;
}

void adjustCurrentFlow()
{
  // B1 current limiting
  if ((battery1Current > -battery1CurrentLimit) && (battery1Current < battery1CurrentLimit)) // current within limits
  {
    if (b1Healthy)
    {  
      if (battery1PWMVal < 255)
      {
        currentMillis = millis();
        if ((battery1PWMVal == 0) && (currentMillis - startMillis >= 15000))
        {
          battery1PWMVal++;
          Serial.println("B1: CURRENT LOWER LIMIT APPLIED FOR THE NEXT 15 SECONDS");
          startMillis = currentMillis;
        }
        else if (battery1PWMVal > 0)
        {
          battery1PWMVal++;
          Serial.println("B1: CURRENT INCREASING TO MANAGE LOAD");
        }
      }
      else
      {
        Serial.println("B1: CURRENT INCREASED TO MAXIMUM");
      }
      if (battery2PWMVal == 155)
      {
        b1CurrentLimited = 0;
      }
    }
    else
    {
      battery1PWMVal = minPWMVal;
      Serial.println("B1: UNHEALTHY - SETTING PWM TO MINIMUM");
    }
  }
  else
  {
    b1CurrentLimited = 1;
    if (battery1PWMVal > 0)
    {
      battery1PWMVal--;
      Serial.println("B1: CURRENT REDUCING TO MANAGE LOAD");
    }
    else
    {
      Serial.println("B1: CURRENT DECREASED TO MINIMUM");
    }
    if (notificationAllowed)
    {
      Blynk.notify("ISOLATOR: CURRENT HIGH!!!");
      notificationAllowed = false;
    }
  }
  //pwmControl(b1PWMChannel, battery1PWMVal, "B1 CURRENT LIMITING PWM"); // disconnect

  /*
  // B2 current limiting
  if ((battery2Current > -battery2CurrentLimit) && (battery2Current < battery2CurrentLimit)) // current within limits
  {
    if (b2Healthy)
    {  
      if (battery2PWMVal < 255)
      {
        currentMillis = millis();
        if ((battery2PWMVal == 0) && (currentMillis - startMillis >= 15000))
        {
          battery2PWMVal++;
          Serial.println("B2: CURRENT LOWER LIMIT APPLIED FOR THE NEXT 15 SECONDS");
          startMillis = currentMillis;
        }
        else if (battery2PWMVal > 0)
        {
          battery2PWMVal++;
          Serial.println("B2: CURRENT INCREASING TO MANAGE LOAD");
        }
      }
      else
      {
        Serial.println("B2: CURRENT INCREASED TO MAXIMUM");
      }
      if (battery2PWMVal == 255)
      {
        b2CurrentLimited = 0;
      }
    }
    else
    {
      battery2PWMVal = minPWMVal;
      Serial.println("B2: UNHEALTHY - SETTING PWM TO MINIMUM");
    }
  }
  else
  {
    b2CurrentLimited = 1;
    if (battery2PWMVal > 0)
    {
      battery2PWMVal--;
      Serial.println("B2: CURRENT REDUCING TO MANAGE LOAD");
    }
    else
    {
      Serial.println("B2: CURRENT DECREASED TO MINIMUM");
    }
    if (notificationAllowed)
    {
      Blynk.notify("ISOLATOR: CURRENT HIGH!!!");
      notificationAllowed = false;
    }
  }
  pwmControl(b2PWMChannel, battery2PWMVal, "B2 CURRENT LIMITING PWM"); // disconnect
  */
}

void adjustFan()
{
  if (systemTemperature > maxAllowedBoardTemp * .75)
  {
    temperatureLimited = 0;
    if (fanPWMVal < maxPWMVal)
    {
      fanPWMVal += 1; // ramp up fan speed
      if (debugPWM)
      {
        Serial.print("FAN: SPEED INCREASING - TEMP APPROACHING LIMIT - PWM value: ");
        Serial.println(fanPWMVal);
      }
    }
  }
  /*else if (systemTemperature > maxAllowedBoardTemp)
  {
    temperatureLimited = 1;
    if (notificationAllowed)
    {
      Blynk.notify("ISOLATOR: PCB TEMPERATURE HIGH!!!");
      notificationAllowed = false;
    }
    if (fanPWMVal < maxPWMVal)
    {
      fanPWMVal += 1; // ramp up fan speed
      if (debugPWM)
      {
        Serial.print("FAN: SPEED INCREASING - TEMP ABOVE LIMIT - PWM value: ");
        Serial.println(fanPWMVal);
      }
    }
    if (battery1PWMVal > minPWMVal)
    {
      battery1PWMVal -= 10; // ramp B1 current down fast
      if (debugPWM)
      {
        Serial.print("B1: Current being reduced, PCB OVERTEMP - PWM value: ");
        Serial.println(battery1PWMVal);
      }
    }
  }
  */
  else
  {
    temperatureLimited = 0;
    if (fanPWMVal > minPWMVal)
    {
      fanPWMVal -= 1; // ramp down fan speed
      if (debugPWM)
      {
        Serial.print("FAN: SPEED REDUCING - TEMP GOOD - PWM Value ");
        Serial.println(fanPWMVal);
      }
    }
    /*
    if (battery1PWMVal < maxPWMVal)
    {
      battery1PWMVal += 1; // ramp B1 current up slow
      if (debugPWM)
      {
        Serial.print("B1: Current being increased, after PCB overtemp, PWM value: ");
        Serial.println(battery1PWMVal);
      }
    }
    */
  }
  if (debugTemp)
  {
    Serial.print("PCB Temp (C): ");
    Serial.println(systemTemperature);
  }
  // set the actual fan speed
  ledcWrite(fanPWMChannel, fanPWMVal);
  // limit B1 current
  //ledcWrite(b1PWMChannel, battery1PWMVal);
}

void updateLimits()
{
  if (battery1Voltage < battery1VoltageMin)
  {
    battery1VoltageMin = battery1Voltage;
  }
  else if (battery1Voltage > battery1VoltageMax)
  {
    battery1VoltageMax = battery1Voltage;
  }
  if (battery2Voltage < battery2VoltageMin)
  {
    battery2VoltageMin = battery2Voltage;
  }
  else if (battery2Voltage > battery2VoltageMax)
  {
    battery2VoltageMax = battery2Voltage;
  }
  if (battery1Current < battery1CurrentMin)
  {
    battery1CurrentMin = battery1Current;
  }
  else if (battery1Current > battery1CurrentMax)
  {
    battery1CurrentMax = battery1Current;
  }
  if (battery2Current < battery2CurrentMin)
  {
    battery2CurrentMin = battery2Current;
  }
  else if (battery2Current > battery2CurrentMax)
  {
    battery2CurrentMax = battery2Current;
  }
}

void pwmControl(int channel, int value, String from)
{
  ledcWrite(channel, value);
  if (channel == 1)
  {
    channelName = "B1";
  }
  else if (channel == 2)
  {
    channelName = "B2";
  }
  else if (channel == 3)
  {
    channelName = "L1";
  }
  else if (channel == 4)
  {
    channelName = "L2";
  }
  else if (channel == 5)
  {
    channelName = "L3";
  }

  if ((debugPWM) && (value > 1))
  {
    Serial.print(channelName);
    Serial.print(" ON ");
    Serial.print(value);
    Serial.print(" ");
    Serial.println(from);
  }
  else if ((debugPWM) && (value <= 1))
  {
    Serial.print(channelName);
    Serial.print(" OFF ");
    Serial.print(value);
    Serial.print(" ");
    Serial.println(from);
  }
}
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
void loop()
{
  timer0.run(); // Initiates BlynkTimer
  server.handleClient();
  button.tick();
  Blynk.run();
  updateConnectionDetails();
}

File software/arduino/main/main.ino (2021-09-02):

#include "Arduino.h"
#include "Wire.h"
#include "ADC128D818.h"
#include <SPI.h>
#include <Adafruit_GFX.h>
#include <Adafruit_SSD1306.h>
#include "BluetoothSerial.h"

#if !defined(CONFIG_BT_ENABLED) || !defined(CONFIG_BLUEDROID_ENABLED)
#error Bluetooth is not enabled! Please run `make menuconfig` to and enable it
#endif

#define SCREEN_WIDTH 128 // OLED display width, in pixels
#define SCREEN_HEIGHT 32 // OLED display height, in pixels
#define OLED_RESET     4 // Reset pin # (or -1 if sharing Arduino reset pin)
#define SCREEN_ADDRESS 0x3C ///< See datasheet for Address; 0x3D for 128x64, 0x3C for 128x32
Adafruit_SSD1306 display = Adafruit_SSD1306(SCREEN_WIDTH, SCREEN_HEIGHT, &Wire, OLED_RESET);

ADC128D818 adc(0x1D);

int updatesInLoop = 5;

BluetoothSerial SerialBT;
int received;// received value will be stored in this variable
char receivedChar;// received value will be stored as CHAR in this variable

const char manualOff ='0';
const char manualOn ='1';
const char l1BtForceOn ='a';
const char l1BtForceOff ='b';
const char l2BtForceOn ='c';
const char l2BtForceOff ='d';
const char l3BtForceOn ='e';
const char l3BtForceOff ='f';
const char b1BtForceOn ='g';
const char b1BtForceOff ='h';
const char b2BtForceOn ='i';
const char b2BtForceOff ='j';

float systemVoltage = 3.0;
float systemTemperature = 25;
float systemVoltageDivider = 1.322; 
float currentVoltageDivider = 1.33;
float batteryVoltageDivider = 7.16;
float milliVoltPerAmp = 0.045;
float b1Voltage = 0.0;
float b2Voltage = 0.0;
float b1Current = 0.0;
float b2Current = 0.0;

char staticTextToDisplay[22] = "Isolator  V0.1";

int maxAllowedBoardTemp = 80;

int autoMode = 1;
int buttonPin = 33;
int sysLedPin = 18; //deprecated
int b1LedPin = 19; //deprecated
int b2LedPin = 23; //deprecated
int b1EnPin = 32;
int b2EnPin = 25;
int l1EnPin = 14;
int l2EnPin = 13;
int l3EnPin = 4;

int pwmValue = 255;
int loopDelay = 500;

bool sysLedBlinkState = HIGH;

long loopTimer;

void setup() {
  Wire.begin();
  Serial.begin(115200);
  //SerialBT.begin("Isolator"); //Bluetooth device name
  adc.begin();
  pinMode(buttonPin, INPUT);
  pinMode(sysLedPin, OUTPUT);
  pinMode(b1LedPin, OUTPUT);
  pinMode(b2LedPin, OUTPUT);
  pinMode(b1EnPin, OUTPUT);
  pinMode(b2EnPin, OUTPUT);
  pinMode(l1EnPin, OUTPUT);
  pinMode(l2EnPin, OUTPUT);
  pinMode(l3EnPin, OUTPUT);
  
  loopTimer = millis();

  // SSD1306_SWITCHCAPVCC = generate display voltage from 3.3V internally
  if(!display.begin(SSD1306_SWITCHCAPVCC, SCREEN_ADDRESS)) {
    Serial.println(F("SSD1306 allocation failed"));
    for(;;); // Don't proceed, loop forever
  }

  display.setRotation(2);
  display.clearDisplay();
  staticText(staticTextToDisplay, " ");
  
}

void loop() {
  receivedChar =(char)SerialBT.read();

  if (Serial.available()) {
    SerialBT.write(Serial.read());
  
  }
  if (SerialBT.available()) {
    SerialBT.print("Received:");// write on BT app
    SerialBT.println(receivedChar);// write on BT app      
    Serial.print ("Received:");//print on serial monitor
    Serial.println(receivedChar);//print on serial monitor    
    //SerialBT.println(receivedChar);//print on the app    
    //SerialBT.write(receivedChar); //print on serial monitor
    
    if(receivedChar == manualOff)
    {
     SerialBT.println("Manual Mode OFF:");// write on BT app
     Serial.println("Manual Mode OFF:");//write on serial monitor
     autoMode = 1;       
    }
    if(receivedChar == manualOn)
    {
     SerialBT.println("Manual Mode ON:");// write on BT app
     Serial.println("Manual Mode ON:");//write on serial monitor 
     autoMode = 0;        
    }
    if(receivedChar == b1BtForceOn)
    {
     SerialBT.println("B1 ON:");// write on BT app
     Serial.println("B1 ON:");//write on serial monitor 
     digitalWrite(b1EnPin, HIGH);      
     digitalWrite(b1LedPin, HIGH);    
    }
    if(receivedChar == b1BtForceOff)
    {
     SerialBT.println("B1 OFF:");// write on BT app
     Serial.println("B1 OFF:");//write on serial monitor
     digitalWrite(b1EnPin, LOW);
     digitalWrite(b1LedPin, LOW);  
    }    
    if(receivedChar == b2BtForceOn)
    {
     SerialBT.println("B2 ON:");// write on BT app
     Serial.println("B2 ON:");//write on serial monitor     
     digitalWrite(b2EnPin, HIGH);  
     digitalWrite(b2LedPin, HIGH);  
    }
    if(receivedChar == b2BtForceOff)
    {
     SerialBT.println("B2 OFF:");// write on BT app
     Serial.println("B2 OFF:");//write on serial monitor
     digitalWrite(b2EnPin, LOW);
     digitalWrite(b2LedPin, LOW);  
    }
    if(receivedChar == l1BtForceOn)
    {
     SerialBT.println("L1 ON:");// write on BT app
     Serial.println("L1 ON:");//write on serial monitor    
     digitalWrite(l1EnPin, HIGH);   
    }
    if(receivedChar == l1BtForceOff)
    {
     SerialBT.println("L1 OFF:");// write on BT app
     Serial.println("L1 OFF:");//write on serial monitor
     digitalWrite(l1EnPin, LOW);   
    }
    if(receivedChar == l2BtForceOn)
    {
     SerialBT.println("L2 ON:");// write on BT app
     Serial.println("L2 ON:");//write on serial monitor   
     digitalWrite(l2EnPin, HIGH);      
    }
    if(receivedChar == l2BtForceOff)
    {
     SerialBT.println("L2 OFF:");// write on BT app
     Serial.println("L2 OFF:");//write on serial monitor
     digitalWrite(l2EnPin, LOW);
    }
    if(receivedChar == l3BtForceOn)
    {
     SerialBT.println("L3 ON:");// write on BT app
     Serial.println("L3 ON:");//write on serial monitor   
     digitalWrite(l3EnPin, HIGH);    
    }
    if(receivedChar == l3BtForceOff)
    {
     SerialBT.println("L3 OFF:");// write on BT app
     Serial.println("L3 OFF:");//write on serial monitor
     digitalWrite(l3EnPin, LOW);
    }   
  }

  if (millis() - loopTimer > loopDelay) {
    loopTimer = millis();
    adcLoop();

    for (int i = 0; i < updatesInLoop; i++) {
      if (i == 0) {
        dtostrf(systemTemperature, 3, 2, staticTextToDisplay);
        staticText("Temp (C):", staticTextToDisplay);
        adcLoop();
      } 
      if (i == 1) {
        dtostrf(b1Voltage, 3, 2, staticTextToDisplay);
        staticText("B1 (V):", staticTextToDisplay);
        adcLoop();
      } 
      if (i == 2) {
        dtostrf(b2Voltage, 3, 2, staticTextToDisplay);
        staticText("B2 (V):", staticTextToDisplay);
        adcLoop();
      } 
      if (i == 3) {
        dtostrf(b1Current, 3, 2, staticTextToDisplay);
        staticText("B1 (A):", staticTextToDisplay);
        adcLoop();
      }
      if (i == 4) {
        dtostrf(b2Current, 3, 2, staticTextToDisplay);
        staticText("B2 (A):", staticTextToDisplay);
        adcLoop();
      }
      updateIsolator();
    }
    Serial.println();
  }
}
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

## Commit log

2020-07-17 Initial commit, Rev1 complete
    [bom.xlsx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]
2020-08-11 Rev 1 Shipped to JLCPCB
    [esp32_battery_isolator-B_Cu.gbr, esp32_battery_isolator-B_Mask.gbr, esp32_battery_isolator-B_Paste.gbr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]
2020-12-29 REV C, take 1
    [REV_A.3mf, REV_B.3mf, bom.xlsx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]
2021-01-04 before removing mosfets
    [esp32_battery_isolator.kicad_pcb, esp32_battery_isolator.sch]
2021-01-05 Rev C - RC1
    enclosure may need some adjusting. Will do a test print and update if needed.
    [REV_A.3mf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]
2021-02-01 REV C off to JLCPCB
    [esp32_battery_isolator-B_Cu.gbr, esp32_battery_isolator-B_Mask.gbr, esp32_battery_isolator-B_Paste.gbr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]
2021-02-05 REV D WIP
    [bom.xlsx, esp32_battery_isolator.kicad_pcb, esp32_battery_isolator.sch]
2021-02-07 REV D complete
    [esp32_battery_isolator-B_Cu.gbr, esp32_battery_isolator-B_Mask.gbr, esp32_battery_isolator-B_Paste.gbr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]
2021-02-07 REV D added board images
    [bom.xlsx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]
2021-02-07 REV D - file cleanup
    [esp32_battery_isolator_bom_jlc.csv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]
2021-02-08 REV D - enclosure, STL, images
    [OLED_0.91_128x32.step, REV_B.3mf, REV_D.3mf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]
2021-02-08 simplified directory structure
    [OLED_0.91_128x32.step, REV_D.3mf, back.stl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]
2021-02-10 Fixed issue with 3D model
    [REV_D.3mf, esp32_battery_isolator.kicad_pcb]
2021-03-09 REV D Complete?
    [bom.xlsx, esp32_battery_isolator.kicad_pcb]
2021-03-10 updated pin definitions for rev c
2021-04-07 REV D Complete - Off to JLCPCB for assembly!
    [esp32_battery_isolator-B_Cu.gbr, esp32_battery_isolator-B_Mask.gbr, esp32_battery_isolator-B_Paste.gbr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]
2021-08-04 REV E - shipped to JLCPCB
    Good to go for JLCPCB assembly service
    [esp32_battery_isolator-B_Cu.gbr, esp32_battery_isolator-B_Mask.gbr, esp32_battery_isolator-B_Paste.gbr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]
2021-08-19 REV F - WIP fixed ground plane issuer around SMPS
    [esp32_battery_isolator.kicad_pcb, esp32_battery_isolator.sch]
2021-09-02 REV F - WIP
    [esp32_battery_isolator.kicad_pcb, esp32_battery_isolator.sch, partitions.csv]
2021-09-04 REV F - off to JLCPCB
    [esp32_battery_isolator-B_Cu.gbr, esp32_battery_isolator-B_Mask.gbr, esp32_battery_isolator-B_Paste.gbr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]
2021-09-10 updating .gitignore and cleaning up
    [partitions.csv]
2021-09-15 app finally stable
    [menu_layout.xlsx]
2021-09-29 Getting closer to finished
    Big changes to the app to make it simpler
    [PrusaSlicer_project.3mf, esp32_battery_isolator.kicad_pcb, esp32_battery_isolator.sch]
2021-11-22 fixed daily couters not resetting
    [REV_D.3mf, REV_G.3mf, back.stl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]
